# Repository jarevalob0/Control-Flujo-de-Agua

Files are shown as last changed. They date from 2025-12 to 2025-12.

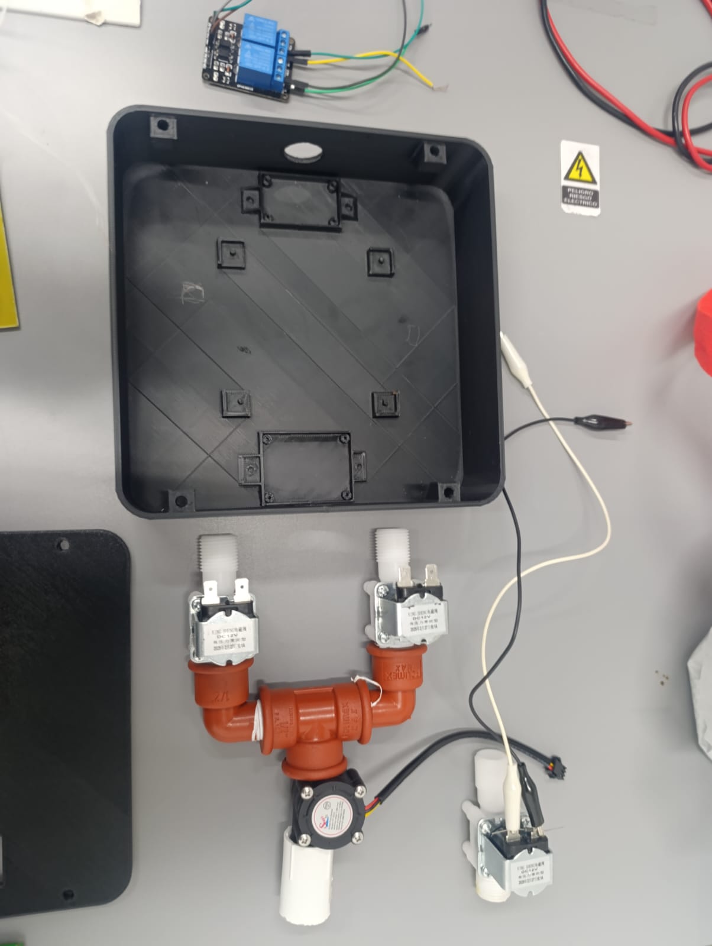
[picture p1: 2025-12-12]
Evidencias/Foto1.jpeg

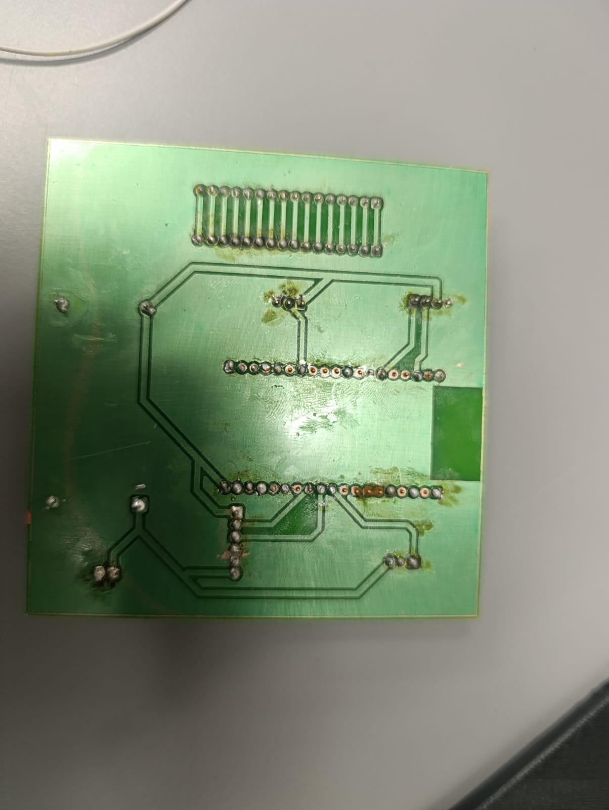
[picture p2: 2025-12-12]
Evidencias/Foto3.jpeg

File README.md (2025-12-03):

# Descripción
Sistema inteligente capaz de medir, registrar y analizar en tiempo real el consumo de agua en viviendas o instalaciones, controlado desde una aplicación móvil.

# Integrantes
SAMUEL CASALLAS

VICTOR ORTIZ

JUAN AREVALO

GABRIEL ALAMO

DANIEL CAMACHO

# Introducción
El proyecto HydroSense surge ante la creciente necesidad de hacer un uso eficiente del agua, un recurso cada vez más limitado debido al cambio climático, el crecimiento poblacional y la falta de sistemas modernos de monitoreo.

En la mayoría de hogares, el consumo de agua no se mide en tiempo real y las personas no tienen forma de saber cuánta agua gastan en actividades comunes. Esto dificulta la adopción de hábitos responsables y limita la capacidad de detectar fugas o consumos inusuales.

HydroSense busca ofrecer una solución de bajo costo que permita medir el uso del agua de manera precisa, accesible y automática, brindando información útil para reducir el desperdicio y promover la conciencia ambiental.

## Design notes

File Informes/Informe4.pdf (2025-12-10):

# CUARTO INFORME PROTOTIPO

### CIRCUITO INTEGRADO A IOT PARA MEDIR Y REDUCIR EL DESPERDICIO DEL AGUA

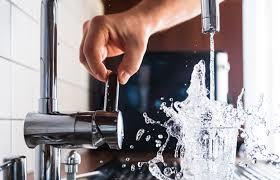
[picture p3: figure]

## EQUIPO

## SAMUEL CASALLAS VICTOR ORTIZ JUAN AREVALO GABRIEL ALAMO DANIEL CAMACHO

INTRODUCCIÓN INGENIERÍA ELECTRÓNICA

1

# OBJETIVO DEL PROTOTIPO

crear una solución innovadora desde la ingeniería electrónica poniendo en práctica conocimientos básicos de los circuitos y nuevas tecnologías

# INTRODUCCIÓN

En el cronograma nos toco lo que es avance de circuito y programación para poder conectar a IOT el prototipo y a la vez documentar errores que hemos cometido por no tener en cuenta ciertos aspectos.

# AVANCES

Ya hemos logrado avanzar con el circuito integrado al ESP32, conectando pantalla LCD con un modulo I2C para simplificar conexiones, conectar los relés y estos conectados a las electroválvulas de 12V.
En cuanto la programación lo que hemos avanzado es calibrar el sensor de flujo y mostrar la información de la cantidad de agua que se esta usando en la pantalla LCD.

ERRORES:

Esta semana compramos la fuente de 12V pero que solo nos da 1 Amperio de corriente, y al tener conectado las electroválvulas en serie y al modulador de voltaje que conecta al ESP32, la corriente que da esta fuente no es suficiente para alimentar todo el sistema del circuito lo que nos genera un atraso en cuanto al cronograma, por lo que la próxima semana se arreglará el problema comprando otra fuente que de la suficiente corriente al sistema.

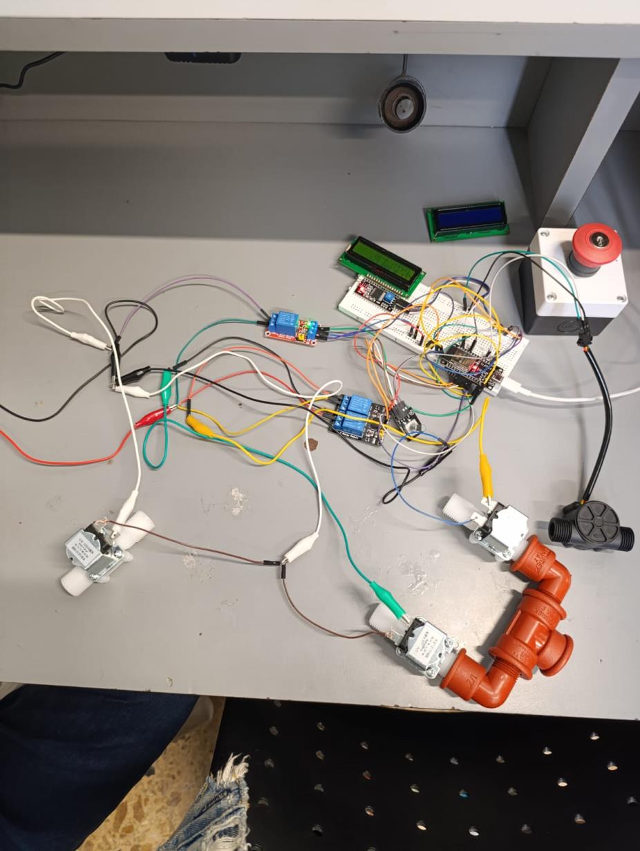
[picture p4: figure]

2

# CONCLUSIONES

Para la próxima semana trabajaremos en arreglar los fallos del circuito, conectar el sistema a IOT y para laboratorio de Electrónica se avanzará con el diagrama esquemático para la creación del PCB.

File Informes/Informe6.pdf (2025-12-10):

# ÚLTIMO INFORME PROTOTIPO

### CIRCUITO INTEGRADO A IOT PARA MEDIR Y REDUCIR EL DESPERDICIO DEL AGUA

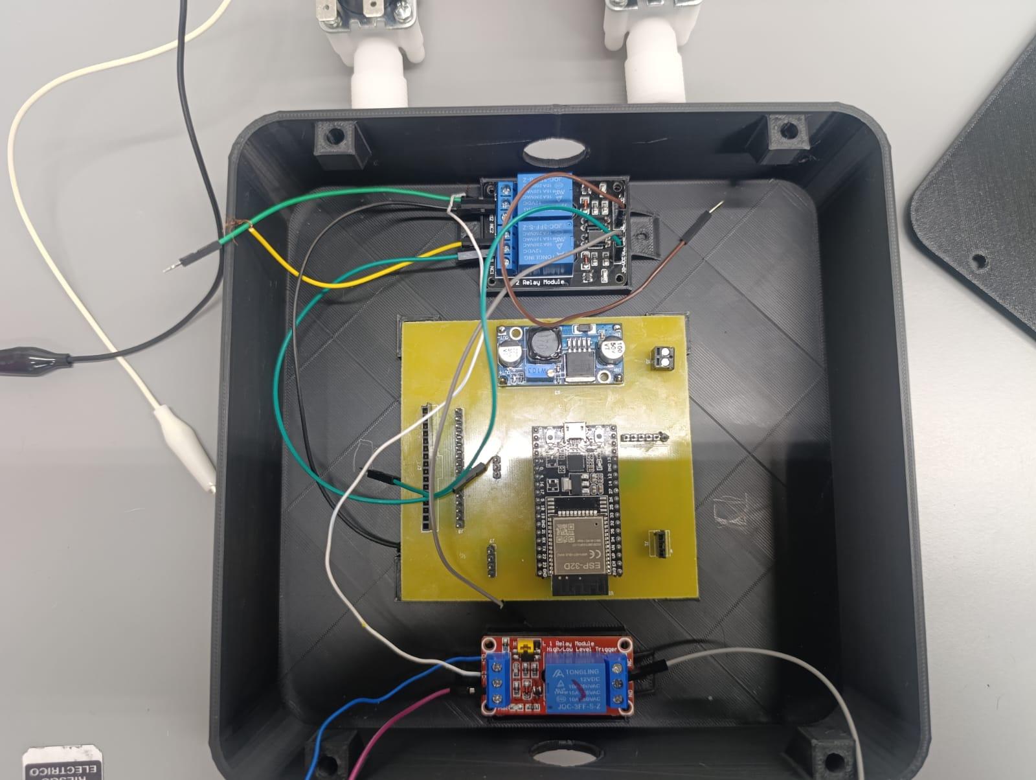
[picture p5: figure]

## EQUIPO: SAMUEL CASALLAS VICTOR ORTIZ JUAN AREVALO GABRIEL ALAMO DANIEL CAMACHO

INTRODUCCIÓN INGENIERÍA ELECTRÓNICA

### OBJETIVO DEL PROTOTIPO

crear una solución innovadora desde la ingeniería electrónica poniendo en práctica conocimientos básicos de los circuitos y nuevas tecnologías

### INTRODUCCIÓN

En nuestro cronograma planificamos que esta semana nos toca la parte de soldar el PCB y el armado del prototipo con su Case correspondiente. Este informe va detallar el avance en estas actividades y lo que nos queda por hacer antes de la fecha de presentación del prototipo que es el 12 de Diciembre.

### AVANCES

Esta semana nos entregaron la PCB fabricada por lo que se soldaron las piezas con las cuales vamos a poder conectar los diferentes componentes al PCB como los relés, pantalla LCD, Electroválvulas y el ESP32.

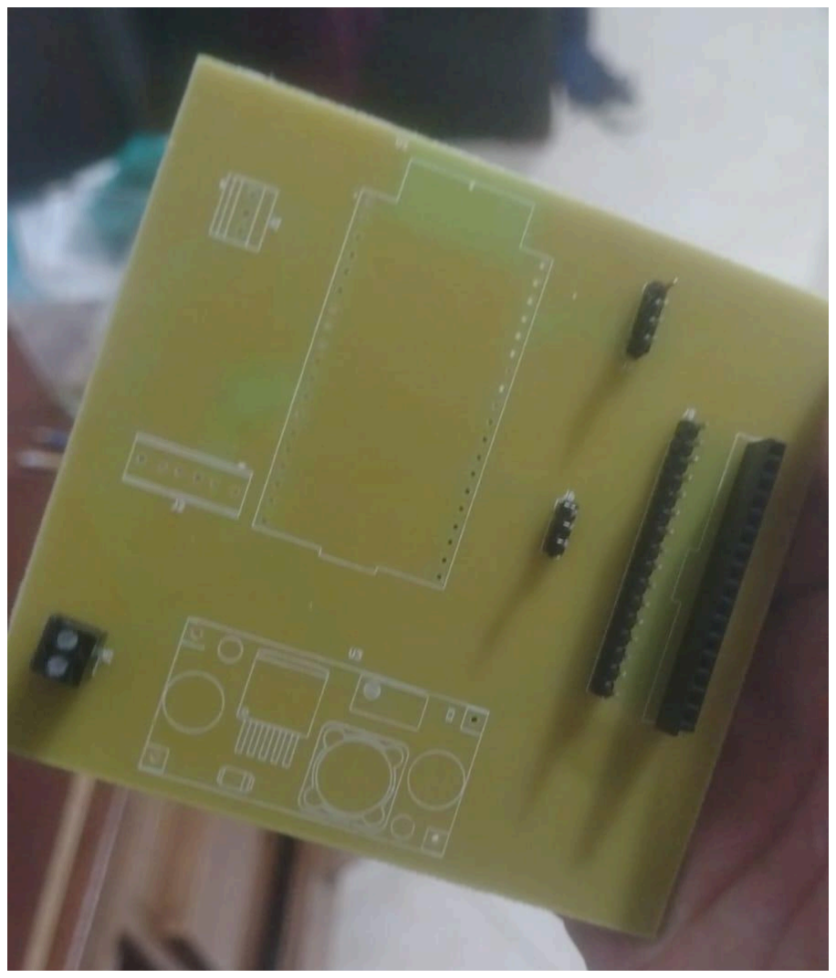
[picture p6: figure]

1

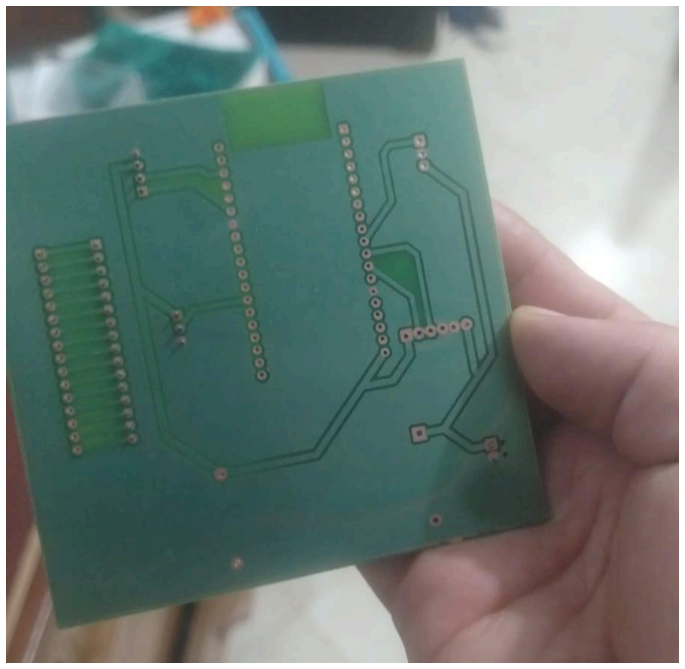
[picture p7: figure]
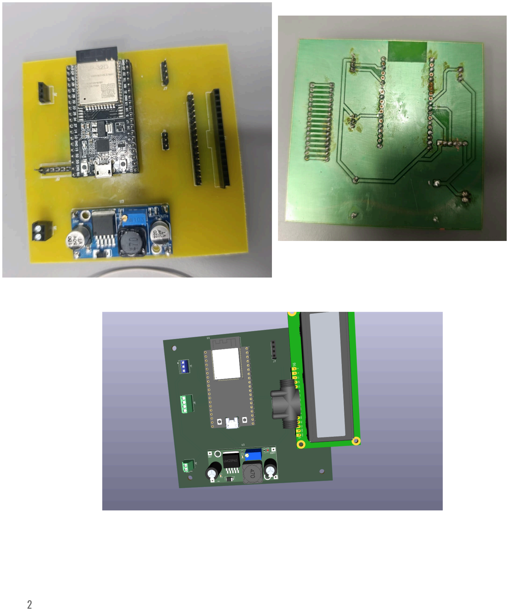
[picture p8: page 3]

2

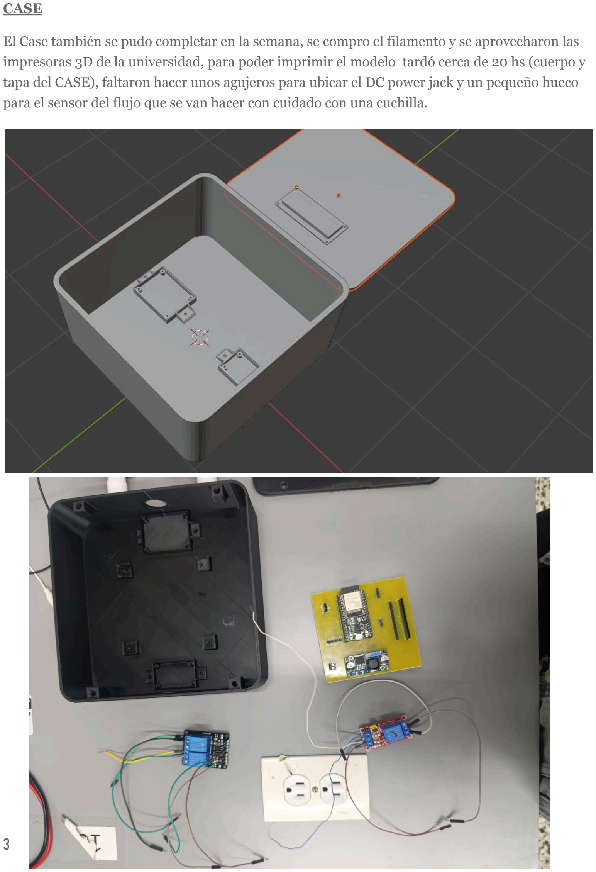
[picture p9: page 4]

CASE

El Case también se pudo completar en la semana, se compro el filamento y se aprovecharon las impresoras 3D de la universidad, para poder imprimir el modelo tardó cerca de 20 hs (cuerpo y tapa del CASE), faltaron hacer unos agujeros para ubicar el DC power jack y un pequeño hueco para el sensor del flujo que se van hacer con cuidado con una cuchilla.

3

### IOT

Se conectó el prototipo a un sistema IOT. se va usar una plataforma con una versión gratuita BLYNK, para controlar el sistema de agua y generar las alertas por el uso excesivo de agua y también poder seleccionar el tipo de agua a usar y sea agua de lluvia o agua potable, hacerlo desde un celular o una computadora conectada a WiFi

4

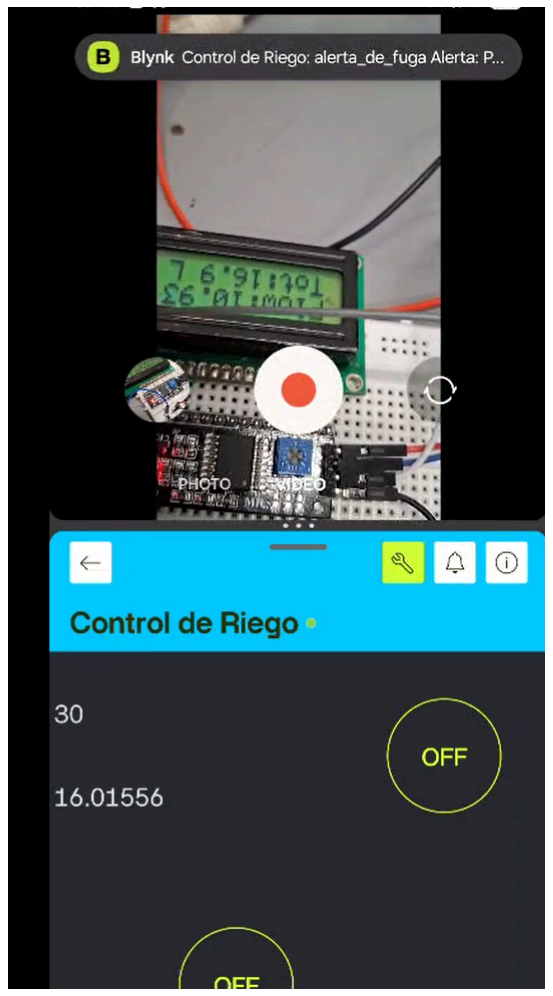
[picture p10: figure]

ERRORES Y ATRASOS

Nuestros errores son de principiantes, esta vez no tuvimos en cuenta en el diseño del case entradas a algunos cables por lo que toca hacer estos ajustes manualmente y con mucho cuidado.

Otro de nuestros errores fue que no sabíamos soldar, además de tener una máquina de soldar en malas condiciones por lo que algunas soldaduras de los pines de la PCB no se ven bien estéticamente.

Con respecto al circuito cuando conectamos todo a la PCB, no funcionaba uno de los relés por lo que sospechamos que pudo haber sido una mala soldadura en el pin que manda los comandos o los cables están en mal estado.

### Lo que nos falta

Para la entrega del prototipo realizaremos los ajustes necesarios a partir de las fallas detectadas en las pruebas previas. Además, evaluaremos su desempeño integrado en un sistema de agua real con el fin de validar su funcionamiento en un entorno operativo.

Como parte de la documentación del proyecto, produciremos un video explicativo que muestre de manera clara el funcionamiento del prototipo. También avanzaremos en el diseño del brochure publicitario, procurando que sea visualmente atractivo, informativo y alineado con la identidad del proyecto.

5

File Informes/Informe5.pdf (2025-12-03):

# QUINTO INFORME PROTOTIPO

### CIRCUITO INTEGRADO A IOT PARA MEDIR Y REDUCIR EL DESPERDICIO DEL AGUA

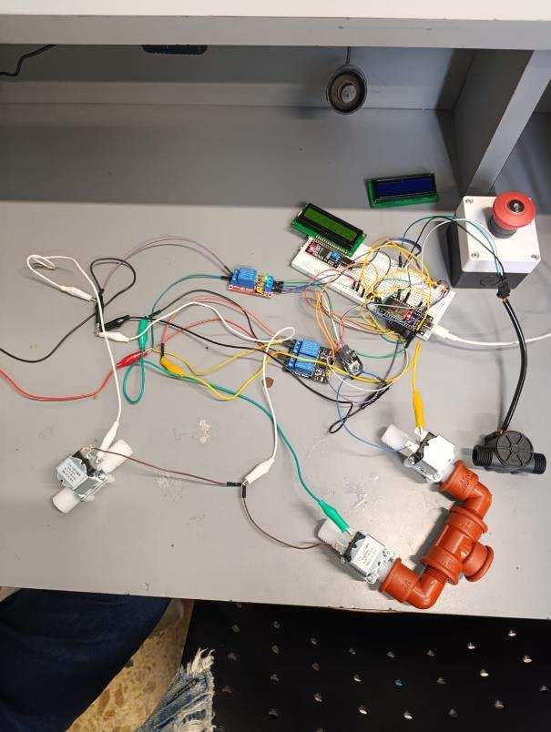
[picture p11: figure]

## EQUIPO: SAMUEL CASALLAS VICTOR ORTIZ JUAN AREVALO GABRIEL ALAMO DANIEL CAMACHO

INTRODUCCIÓN INGENIERÍA ELECTRÓNICA

# OBJETIVO DEL PROTOTIPO

crear una solución innovadora desde la ingeniería electrónica poniendo en práctica conocimientos básicos de los circuitos y nuevas tecnologías

# INTRODUCCIÓN

En este informe hablaremos de avances que llevamos con laboratorio de electrónica, errores y lo que nos queda por hacer en las semanas que quedan.

# AVANCES

En laboratorio de electrónica se nos propuso hacer el PCB y un CASE para el prototipo que se está armando.
Ya se logró terminar el diseño de La PCB por lo que nos falta que profesor de laboratorio revisé nuestro diseño para luego mandar a fabricar la placa y proceder a soldar los componentes a la misma. El encargado de la PCB es Samuel casallas que también esta trabajando con Víctor Ortiz en el circuito.

En cuanto al circuito, todavía se esta viendo que el golpe electromagnético de las electroválvulas cuando prenden y apaga no afecte al microcontrolador

# Adelanto PCB

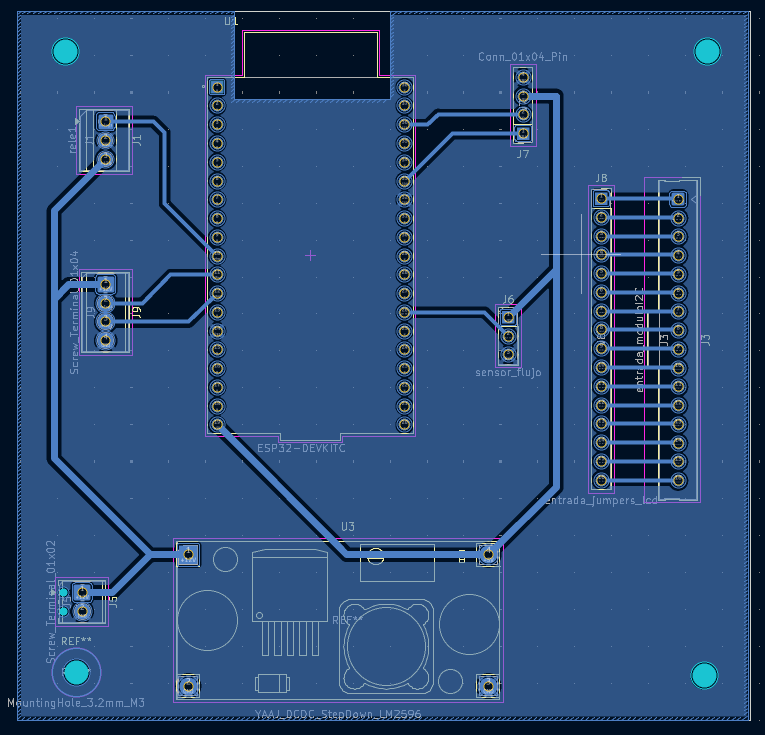
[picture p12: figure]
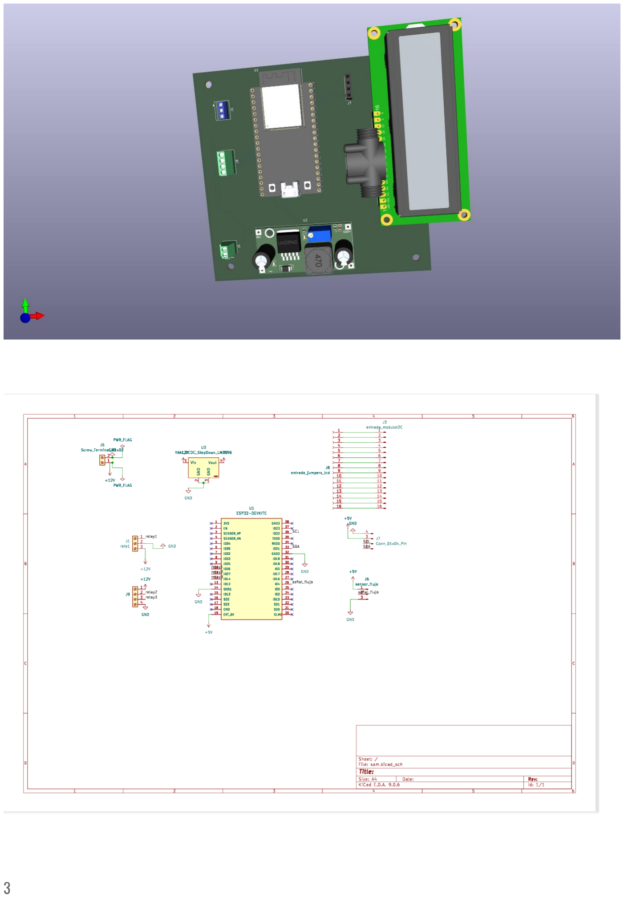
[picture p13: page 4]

CASE

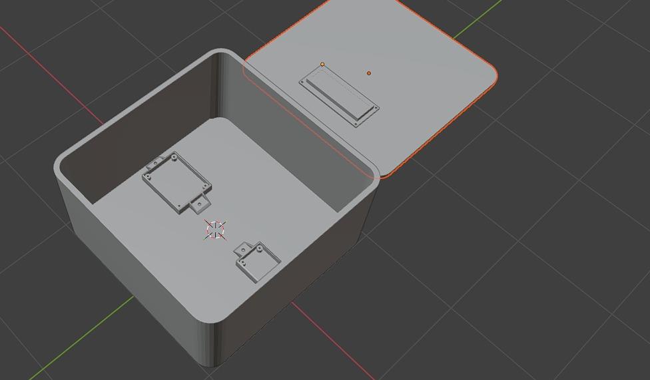
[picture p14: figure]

Todavía falta darle mas diseño al case, aun se sigue trabajando en el case para ya la próxima semana mandar a fabricar el case y hacer primeras pruebas con el circuito.

ERRORES Y ATRASOS:

En la semana tuvimos una falla, mientras hacíamos el circuito de 12V que conecta a los relés y las electroválvulas conectamos por error el ESP32 a la fuente de 12V lo que nos quemo el microcontrolador, un error que facilito el diseño de la PCB ya que el footprint del ESP32 que se quemó no se encontraba en internet y el que se compró si se encontró fácilmente.
Esta semana nuestro compañero Juan Arévalo el encargado de la programación y comunicación del ESP32 con un sistema IOT no realizo avances por lo que en este sector no se realiza documentación por ahora

# CONCLUSIONES

Esperamos que el profesor de laboratorio nos de el ok con el modelo de la PCB así poder proseguir a soldar los componentes y sumarlo al case para llegar a la fecha de presentación del prototipo y poder probarlo con un sistema de agua.

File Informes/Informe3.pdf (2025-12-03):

# TERCER INFORME PROTOTIPO

### CIRCUITO INTEGRADO A IOT PARA MEDIR Y REDUCIR EL DESPERDICIO DEL AGUA


## EQUIPO

## SAMUEL CASALLAS VICTOR ORTIZ JUAN AREVALO GABRIEL ALAMO DANIEL CAMACHO

INTRODUCCIÓN INGENIERÍA ELECTRÓNICA

# INTRODUCCIÓN

Esta semana se ha adelantado con otras componentes que nos van ayudar con la conexión del circuito y cuidando cada componente de no dañarlos y a la vez también se adelanta en la documentación de laboratorio de electrónica.

# OBJETIVO DEL PROTOTIPO

crear una solución innovadora desde la ingeniería electrónica poniendo en práctica conocimientos básicos de los circuitos y nuevas tecnologías

# COMPONENTES ELECTRÓNICOS

1. Caudalímetro
2. electroválvulas
3. Microprocesador ESP32
4. Arduino
5. IOT
6. Pantalla LCD 16x2

Estos componentes son los que compramos la semana pasada, y esta semana se compraron mas componentes para poder facilitar las conexiones de los circuitos y cuidar de no dañar los componentes.

7. Relés de 12V a 3.3V
8. Un cargador de 12V y con corriente de 1ª
9. Un I2C para simplificar conexiones de la pantalla LCD

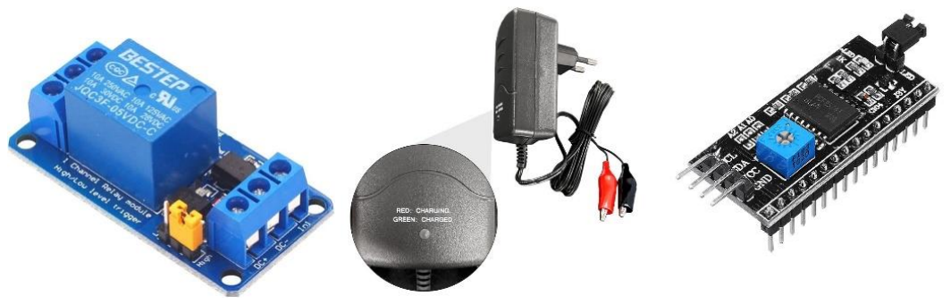
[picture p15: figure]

# DIAGRAMA CAJA NEGRA

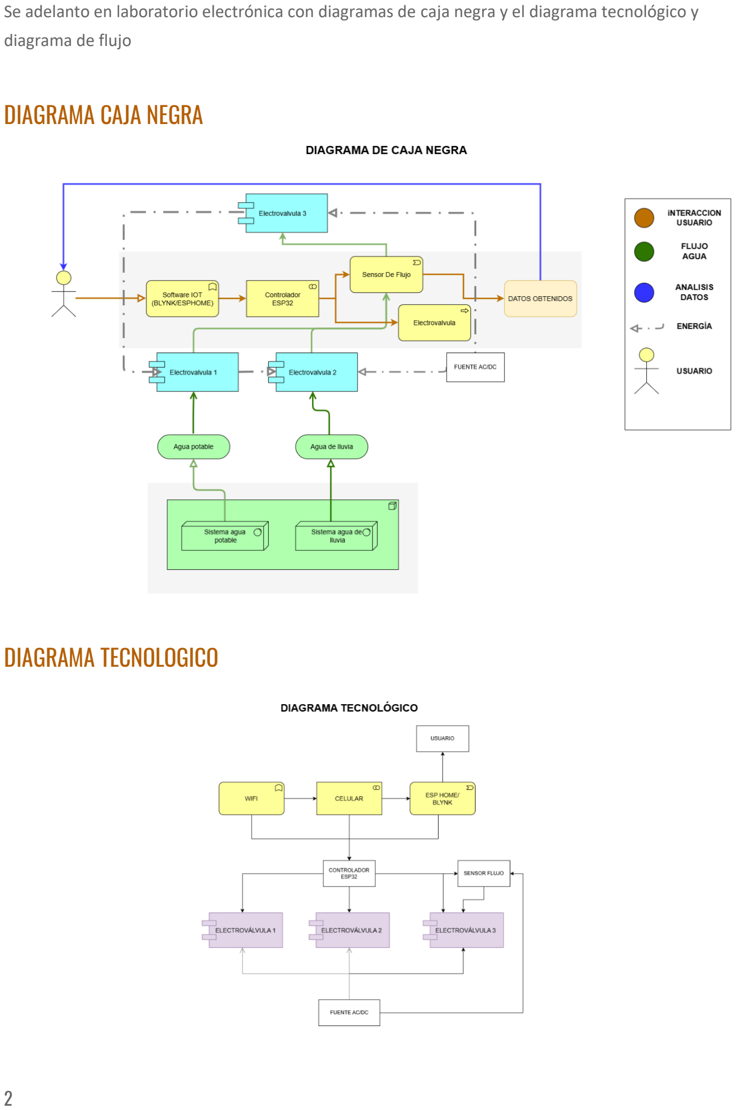
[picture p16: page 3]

Se adelanto en laboratorio electrónica con diagramas de caja negra y el diagrama tecnológico y diagrama de flujo

# DIAGRAMA TECNOLOGICO

# DIAGRAMA DE FLUJO

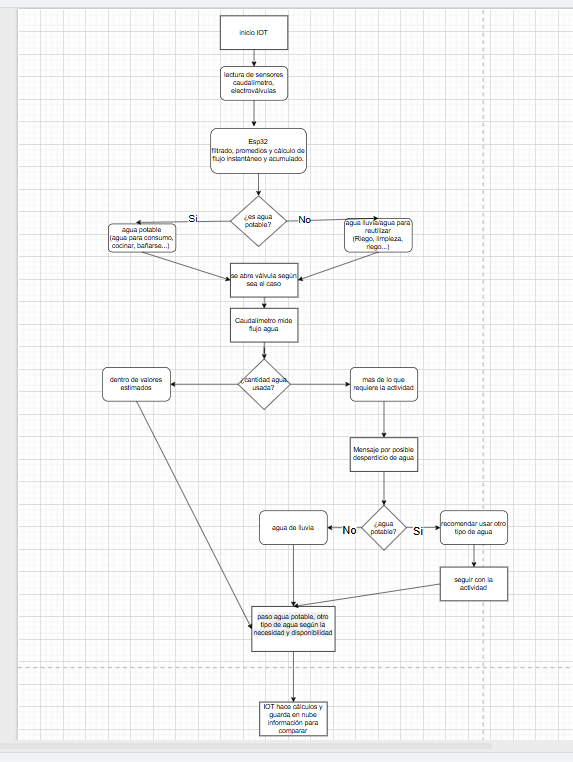
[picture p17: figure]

# CONCLUSIONES

La próxima semana se dedicara a trabajar en solo el diagrama de conexiones, montar el circuito, calibración del sensor.

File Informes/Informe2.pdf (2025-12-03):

# SEGUNDO INFORME PROTOTIPO

CIRCUITO INTEGRADO A IOT PARA MEDIR Y REDUCIR EL DESPERDICIO DEL AGUA

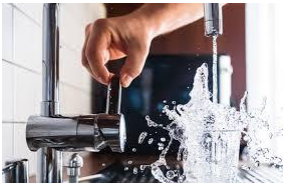
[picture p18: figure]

## EQUIPO

## SAMUEL CASALLAS VICTOR ORTIZ JUAN AREVALO GABRIEL ALAMO DANIEL CAMACHO

INTRODUCCIÓN INGENIERÍA ELECTRÓNICA

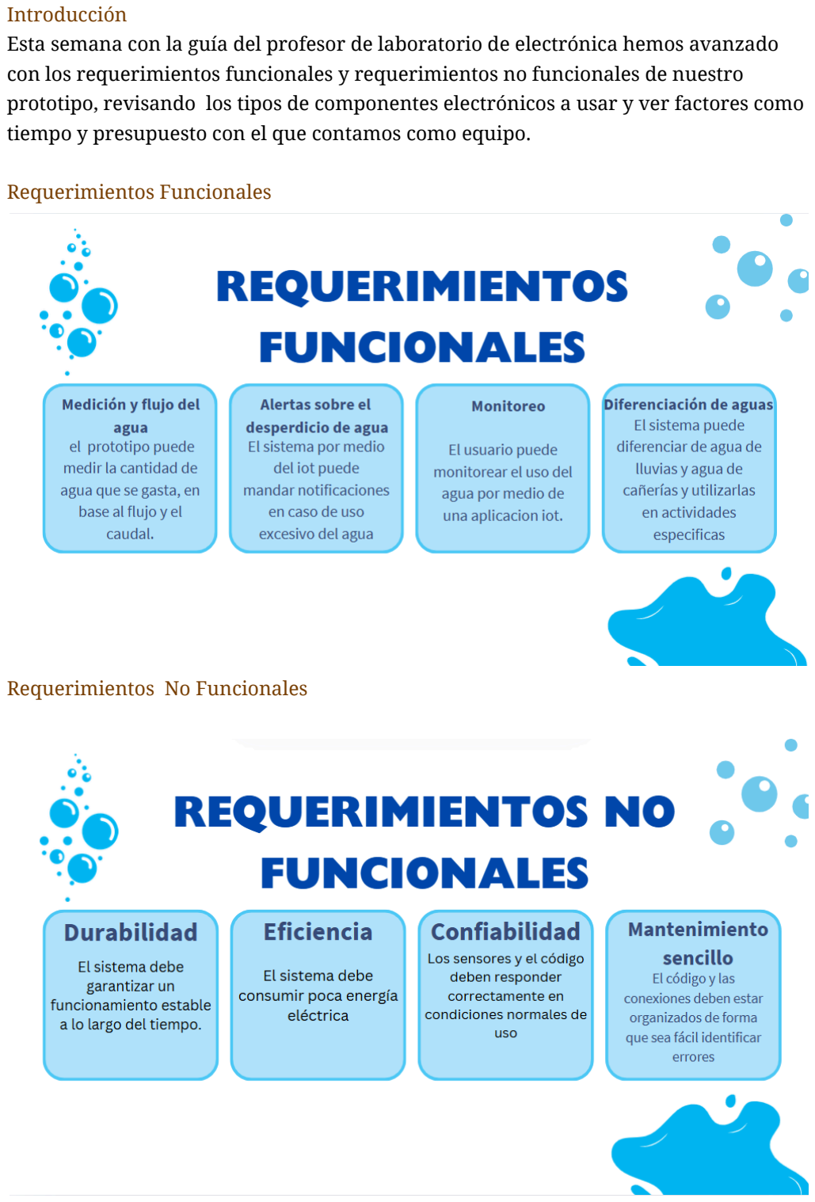
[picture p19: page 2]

Introducción
Esta semana con la guía del profesor de laboratorio de electrónica hemos avanzado con los requerimientos funcionales y requerimientos no funcionales de nuestro prototipo, revisando los tipos de componentes electrónicos a usar y ver factores como tiempo y presupuesto con el que contamos como equipo.

Requerimientos Funcionales

Requerimientos No Funcionales

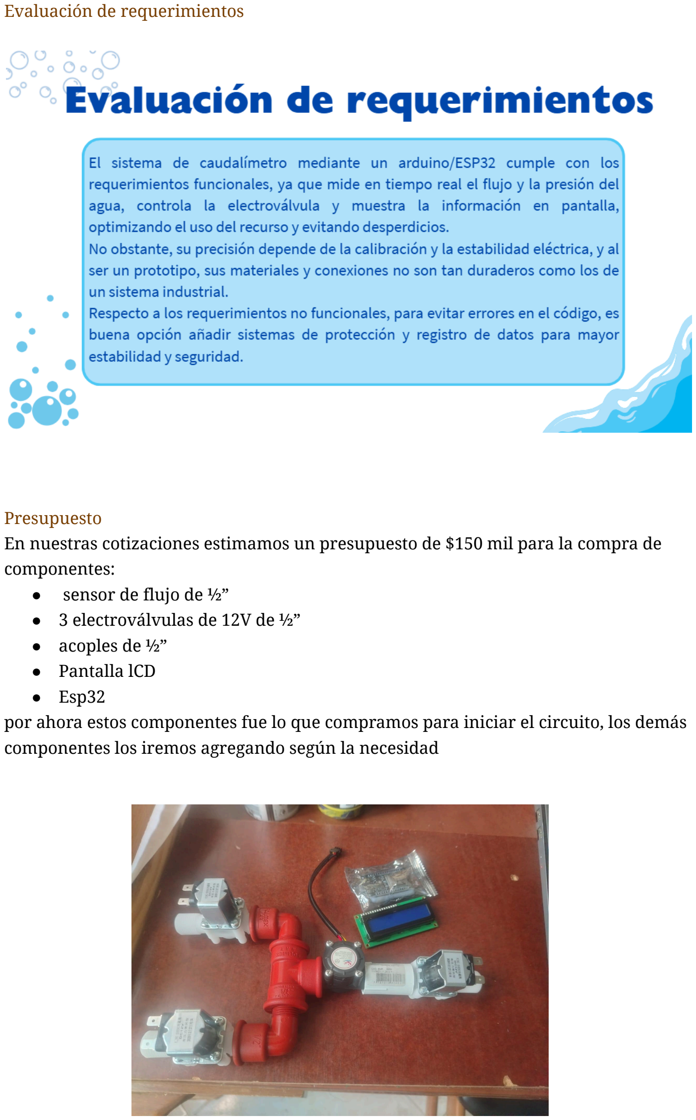
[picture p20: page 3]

Evaluación de requerimientos

Presupuesto
En nuestras cotizaciones estimamos un presupuesto de $150 mil para la compra de componentes:
- sensor de flujo de ½”
- 3 electroválvulas de 12V de ½”
- acoples de ½”
- Pantalla lCD
- Esp32
por ahora estos componentes fue lo que compramos para iniciar el circuito, los demás componentes los iremos agregando según la necesidad

Diagrama De Flujo del prototipo

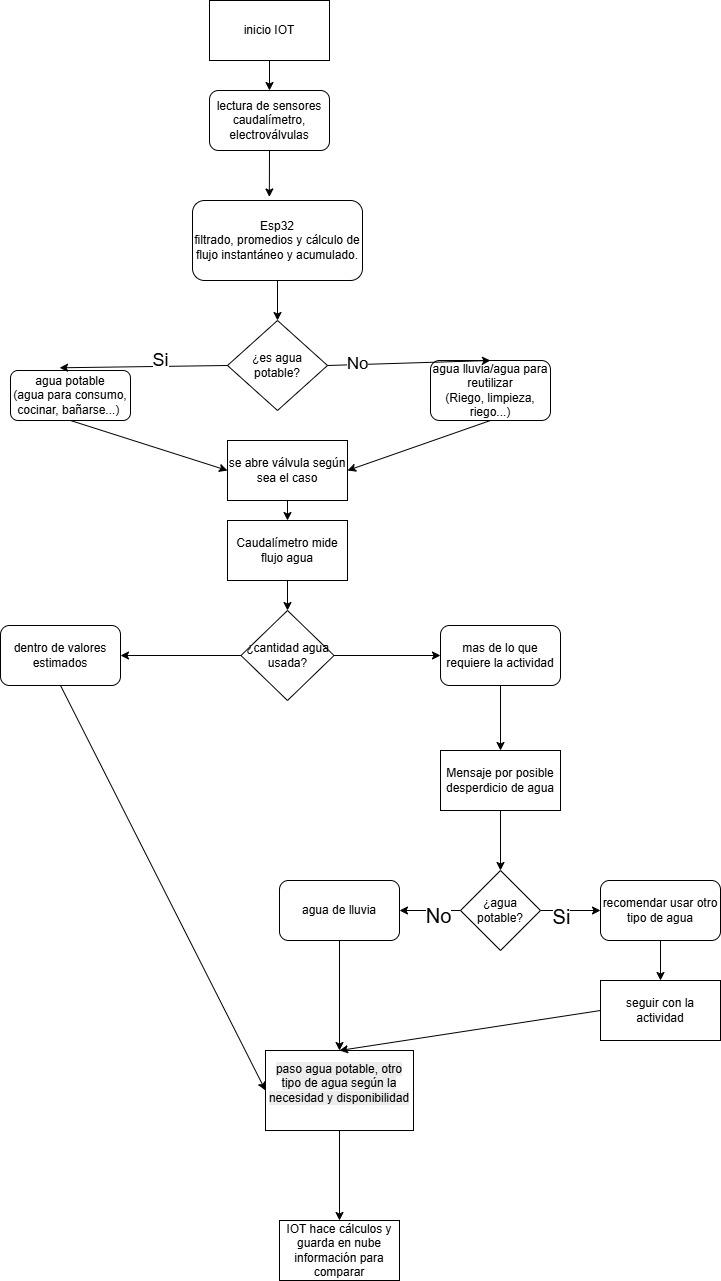
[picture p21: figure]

Conclusiones
Para la próxima semana según nuestro cronograma estaremos trabajando en el circuito, calibración del sensor y ajustando la programación del sensor de flujo, a la vez estaremos trabajando en la documentación del taller de laboratorio de electrónica.

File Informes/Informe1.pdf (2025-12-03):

# PRIMER INFORME PROTOTIPO

CIRCUITO INTEGRADO A IOT PARA MEDIR Y REDUCIR EL DESPERDICIO DEL AGUA

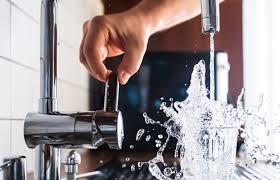
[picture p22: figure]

## EQUIPO

## SAMUEL CASALLAS VICTOR ORTIZ JUAN AREVALO GABRIEL ALAMO DANIEL CAMACHO

INTRODUCCIÓN INGENIERÍA ELECTRÓNICA

## INTRODUCCIÓN

En el cronograma estipulamos que esta primera semana investigaremos acerca de los componentes electrónicos que vamos a utilizar en el prototipo dando una solución a nuestra problemática que es el desperdicio de agua, a su vez explicaremos qué ventajas, desventajas y los límites de estos componentes

## OBJETIVO DEL PROTOTIPO

crear una solución innovadora desde la ingeniería electrónica poniendo en práctica conocimientos básicos de los circuitos y nuevas tecnologías

## COMPONENTES ELECTRÓNICOS

1. Caudalimetro
2. electroválvulas
3. Microprocesador ESP32
4. Arduino
5. IOT

Ahora daremos paso a explicar el porqué usaremos cada uno de los componentes y con qué finalidad, así como sus ventajas y desventajas.

1

## CAUDALIMETRO

Para el prototipo usaremos un sensor de flujo de agua YF-S201 de ¾” qué va medir el paso del agua, el sensor funciona mediante un rotor interno que gira con el paso del agua. Este movimiento hace que un imán dentro del rotor pase repetidamente por un sensor de efecto hall, el cual genera una señal de pulsos y esté conectado a un arduino o microprocesador nos permitirá calcular el caudal de agua que pasa.

Este sistema nos permitirá calcular la cantidad de agua que se está usando para cierta actividad y trabajar con estos datos desde un software y hacer estimaciones de consumo de agua para las actividades en que se usa.

como limitante de este componente electrónico es que por diseño este sensor sólo puede calcular caudales de 1 litros/min-30 litros/min lo que no no va medir si hay fuga en el sistema si no supera ese valor mínimo de 1 litro/min, además de su área de sección es de ¾” lo que sirve para conecciones con mangueras o pvc de este diámetro únicamente, también son susceptibles a atorarse con mugre del agua que se va acomulando, lo que requiere una limpieza del componente.

2

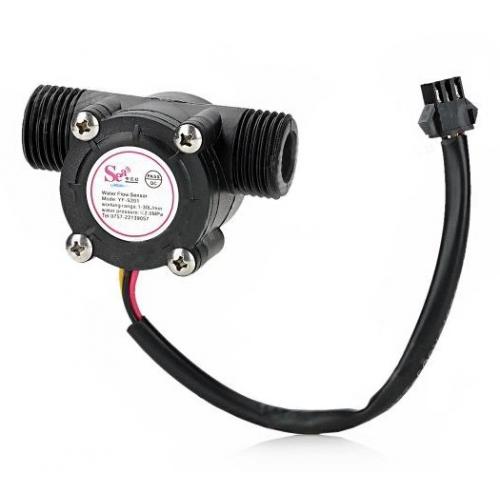
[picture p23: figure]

## ELECTROVÁLVULAS

Elegimos las electroválvulas porque nos permiten controlar de forma automática el paso del agua dentro del sistema, sin tener que hacerlo manualmente. Este componente se activa mediante una señal eléctrica del microcontrolador, abriéndose o cerrándose según las condiciones del circuito.

También cumple otra función: regular el flujo de agua durante cada actividad, evitando desperdicios y permitiendo medir con precisión el consumo real. Esta nos permite que el sistema pueda detener el paso del agua cuando no se está utilizando o cuando se alcanza el volumen establecido , haciendo el proceso más eficiente y controlado.

En nuestro proyecto se plantea el uso de dos fuentes de agua: el agua del sistema de acueducto y el agua de lluvia recolectada. Para controlar el flujo desde cada fuente se utilizaran dos electroválvulas, una en la entrada que regula de donde proviene el agua, y otra en la salida que controla cuando se libera el caudal hacia la actividad correspondiente.

El sistema dará prioridad al uso del agua de lluvia, aprovechando este recurso natural y reduciendo la dependencia del acueducto. De esta manera se busca optimizar el consumo de agua potable, fomentar el uso sostenible de los recursos hídricos y disminuir el desperdicio, integrando la medición de caudal y el control automático mediante las electroválvulas.

3

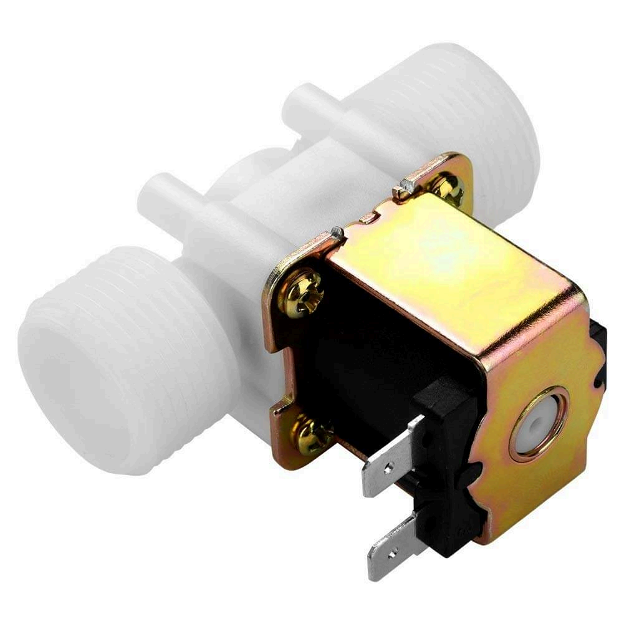
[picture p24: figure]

## MICROPROCESADOR ESP32

El ESP32 es un microprocesador programable que recibe información de sensores, la procesa y controla otros dispositivos (como bombas, válvulas o motores) de forma automática o remota.

El ESP32 es el encargado de leer, interpretar y procesar la información que es generada por el caudalímetro. Gracias a la capacidad del microprocesador de poder conectarse a una red wifi o bluetooth se usará para subir los datos a la nube y poder monitorearlos desde una aplicación de forma remota o para almacenar los datos del consumo total.

## IOT:

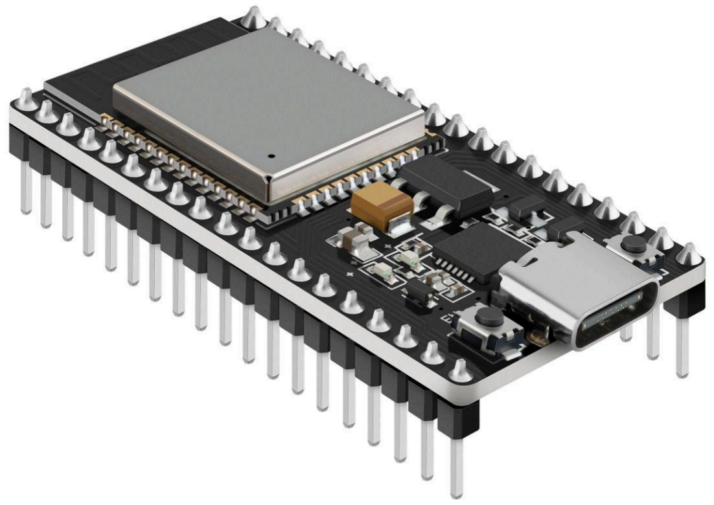
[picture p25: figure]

Usaremos la plataforma Blynk 2.0, para involucrar el IOT en nuestro proyecto, nos permitirá conectar el controlador esp32 a la nube para poder manejar nuestro proyecto con una aplicación desde nuestro celular. Esta aplicación tendrá como principales funciones el monitoreo del flujo de agua, poder calcular el agua necesaria para la actividad que desee el usuario, pudiendo éste configurar el agua que se quiera usar para la actividad que elija, y dar la opción al usuario de poder manejar el mismo las electroválvulas. Ventajas: La plataforma cuenta con un plan gratuito, lo que nos abarata los costes del proyecto. Desventajas: Este plan gratuito nos limita en la cantidad de dispositivos que pueden estar conectados, también solo almacena datos de por un tiempo limitado de una semana, lo cual podría ser un problema a futuro.

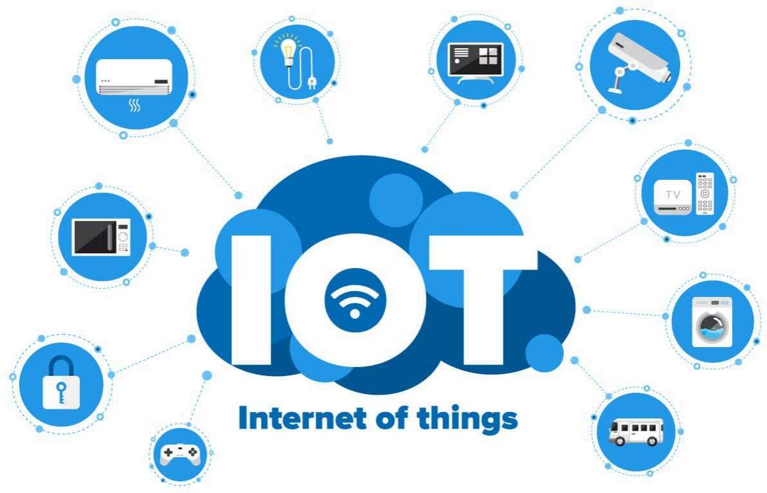
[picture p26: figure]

4

## ARDUINO

El Arduino es el componente principal del sistema de control, este funciona como el cerebro del prototipo, ya que su función es recibir toda la información que le envían los distintos sensores, procesar esos datos para luego ejecutar las acciones programadas, como en el caso de nuestro proyecto, abrir o cerrar la válvula de paso de agua mediante una electroválvula controlada electrónicamente.

Se decidió usar el arduino porque ofrece una manera sencilla
y simple de programar al estar basado en el lenguaje de
C/C++, ya que permite escribir y cambiar el código con


facilidad. Además de esto el arduino tiene la capacidad de ser compatible con un montón de sensores, lo que en nuestro caso, nos facilita la conexión del caudalímetro o el sensor de presión. Su bajo costo y disponibilidad lo hace de las mejores opciones para proyectos de este estilo, sin necesidad de tener equipos industriales costosos.

Dentro del contexto del proyecto, la funcionalidad del arduino es, en primer lugar, recibir las señales eléctricas enviadas por los sensores y las convierte en valores numéricos (como litros por minuto o presión PSI). Luego, analiza los datos en tiempo real y los compara con los límites previamente establecidos, de esa forma poder controlar el flujo del agua de forma automática. Finalmente, el Arduino también se encarga del monitoreo del sistema, permitiendo visualizar la información en una pantalla. Esto facilita observar parámetros como el caudal, la presión o el tiempo de uso.

5

## CONCLUSIÓN

Con la investigación definimos qué componentes electrónicos pueden ser de utilidad para nuestro prototipo y qué papel jugarán en el circuito, el reto será coordinar estos componentes para realizar el objetivo que nos propusimos con nuestro prototipo integrando otros componentes electrónicos como cables, resistencias, etc.

## REFERENCIAS

1. https://alfaiot.com/iot/que-es-arduino-todo-lo-que-necesitas-saber/
2. https://electronilab.co/tienda/electrovalvula-valvula-selenoide-agua-12-vdc-3-4/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
3. https://laredelectronica.com/wp-content/uploads/2020/04/2-16.jpg

6

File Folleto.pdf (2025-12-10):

## ¿ P O R Q UE N E C ESI T AMO S U N A


## SISTEMA I N TELIGE N TE?

# SISTEMA

Q UE MI D E,

# D ETE C T A Y

C O N T R O L A .

## H A Z TU C O N SUMO D E AGUA MÁ S EFI C IE N TE. ¡ P RUÉBA L A !

## TU S O LUC I Ó N : U N SISTEMA Q UE

P IE N S A P O R T I.

## SISTEMA I N TELIGE N TE US O D E AGUA

- DESPERDICIO INNECESARIO
DE AGUA
- AUMENTO EN LA FACTURA
DEL SERVICIO
- USO INEFICIENTE DE AGUA
POTABLE PARA TAREAS
BÁSICAS
- FALTA DE CONTROL Y
VISIBILIDAD DEL CONSUMO
REAL

EL CONSUMO DIARIO DE AGUA ES MAYOR DE LO QUE CREEMOS. MUCHAS VECES USAMOS AGUA POTABLE PARA TAREAS SIMPLES SIN DARNOS CUENTA DEL COSTO NI DEL IMPACTO AMBIENTAL. A ESTO SE SUMA QUE LA MAYORÍA DE PERSONAS NO SABE CUÁNTOS LITROS CONSUME AL REGAR, LAVAR O LIMPIAR, Y TAMPOCO DISTINGUE SI ESTÁ USANDO AGUA DE LLUVIA O AGUA POTABLE, LO QUE GENERA:

AHORRA AGUA, REDUCE
COSTOS Y USA SOLO LO
NECESARIO CON TOTAL
PRECISIÓN.

### - PANTALLA LED CON LECTURA EXACTA DE LITROS POR MINUTO - DETECCIÓN AUTOMÁTICA DE AGUA POTABLE O DE LLUVIA - VÁLVULAS INTELIGENTES SEGÚN TIPO DE AGUA - CONTROL TOTAL PARA EVITAR DESPERDICIOS

# ESPECIFICACIONES TÉCNICAS

TAREA.; US A R AGUA N U N C A H ABÍ A SI D O T A N I N TELIGE N TE; H A Z D E TU C O N SUMO U N A A C C I Ó N R ES P O N S ABLE

BE N EFI C I O S Q UE
T R A N SF O RMA N
TU C O N SUMO

MATERIAL DE LA MANGUERA: PVC
REFORZADO DE ALTA RESISTENCIA
RANGO DE MEDICIÓN: 1–60 LITROS
POR MINUTO
PRECISIÓN DEL CAUDALÍMETRO:
PANTALLA: LED RETROILUMINADA
DE ALTO CONTRASTE
SENSORES: IDENTIFICAN
AUTOMÁTICAMENTE AGUA
POTABLE O AGUA DE LLUVIA
VÁLVULAS: APERTURA Y CIERRE
AUTOMÁTICO SEGÚN TIPO DE
AGUA DETECTADA
CONECTORES: COMPATIBLES CON
GRIFOS ESTÁNDAR
ALIMENTACIÓN DEL MÓDULO:
BATERÍA RECARGABLE POR USB
LONGITUDES DISPONIBLES: 5 M, 10
GARANTÍA: 1 AÑO CONTRA
DEFECTOS DE FABRICACIÓN

• AHORRA AGUA GRACIAS A
LA MEDICIÓN PRECISA DEL

CAUDAL.
• REDUCE TU FACTURA
CONTROLANDO CUÁNTOS
LITROS USAS EN CADA

NUESTRO SISTEMA INTELIGENTE TE
AYUDA A CONTROLAR TU CONSUMO DE
AGUA, EVITAR EL DESPERDICIO Y
OPTIMIZAR CADA USO DIARIO.
APROVECHA MEJOR EL AGUA DE
LLUVIA, USA AGUA POTABLE SOLO
CUANDO ES NECESARIO Y DISFRUTA DE
UNA TECNOLOGÍA PENSADA PARA
CUIDAR TU BOLSILLO Y TU ENTORNO.

• APROVECHA EL AGUA DE
LLUVIA DE FORMA
AUTOMÁTICA Y SEGURA.
• EVITA EL DESPERDICIO DE
AGUA POTABLE, USÁNDOLA

SOLO DONDE
CORRESPONDE.
• IDEAL PARA RIEGO,
LIMPIEZA, AUTOS Y
MANTENIMIENTO DIARIO.
• MAYOR SEGURIDAD: EVITA
MEZCLAR AGUA NO APTA EN
TAREAS SENSIBLES.
• INSTALACIÓN RÁPIDA Y
USO INTUITIVO.

¡ D A EL PA S O H AC I A U N CO N SUMO MÁ S

I N TEL IGE N TE Y EFI C IE N TE!

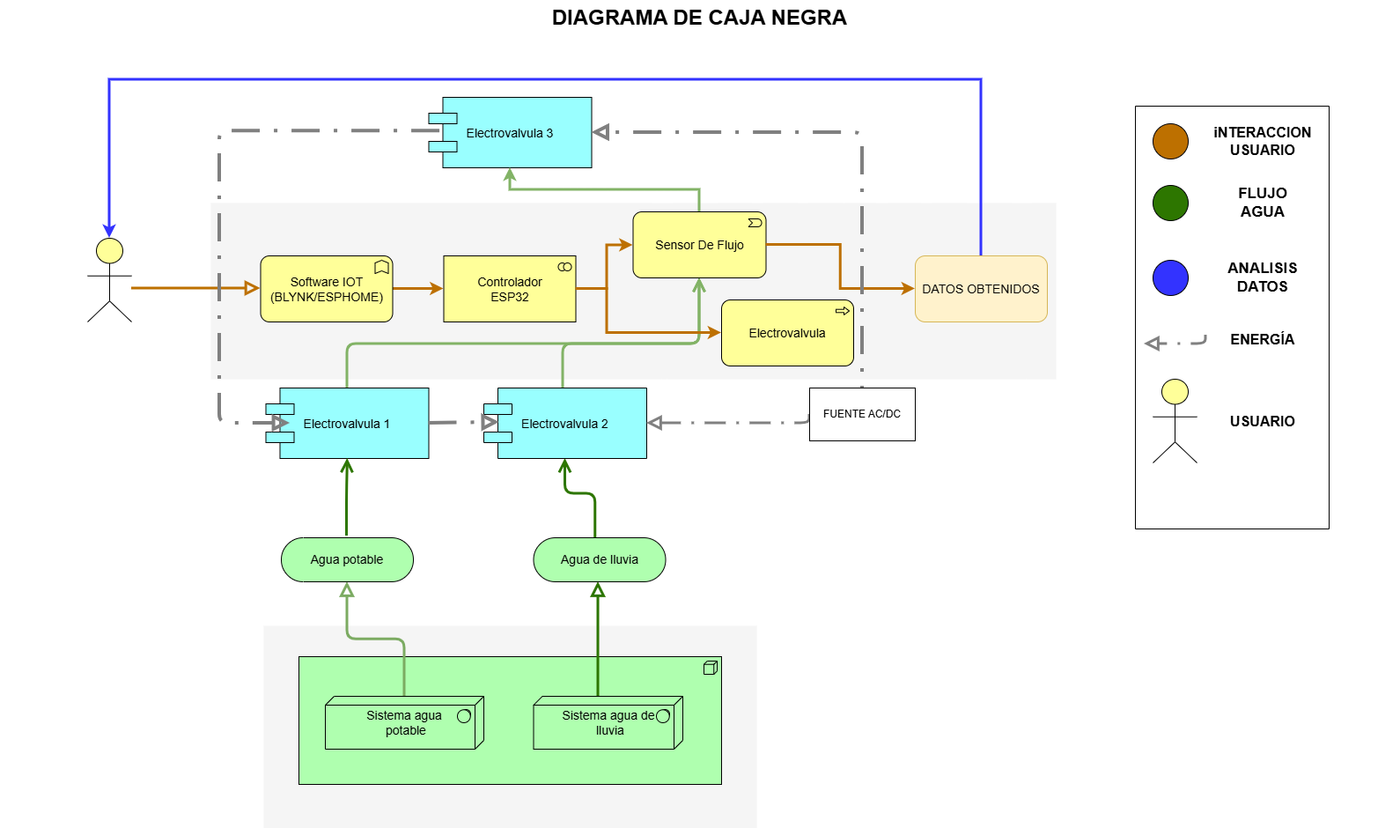
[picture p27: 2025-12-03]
Diagramas/DiagramaDeCaja.png

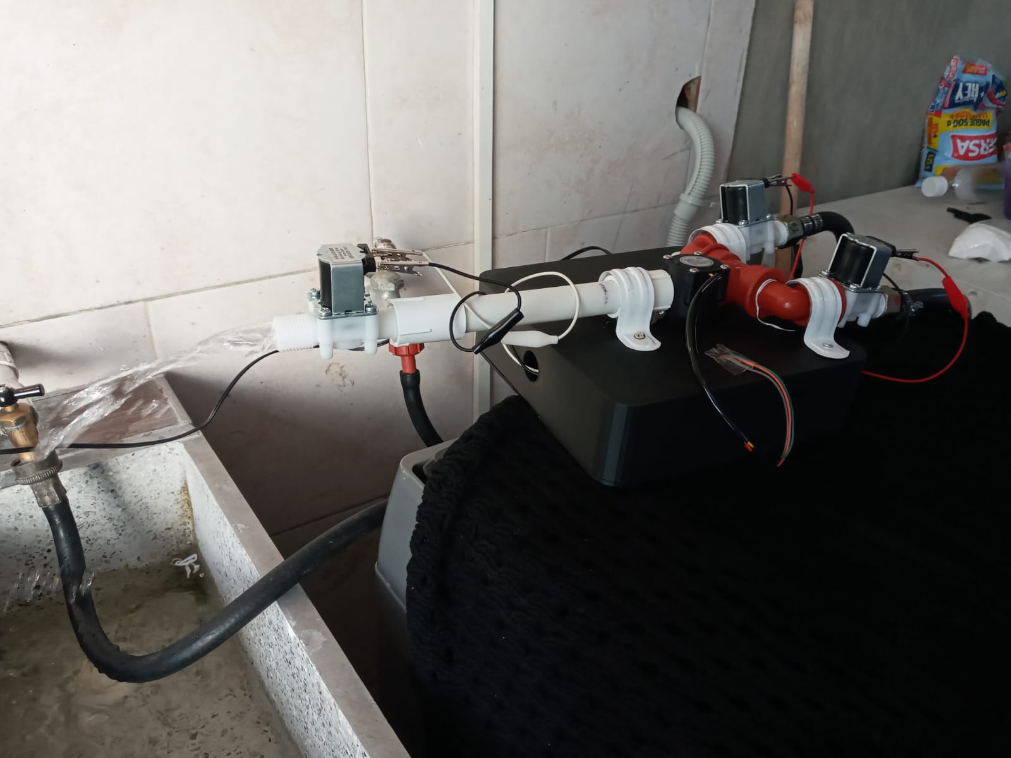
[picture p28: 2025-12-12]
Evidencias/Foto8.jpeg

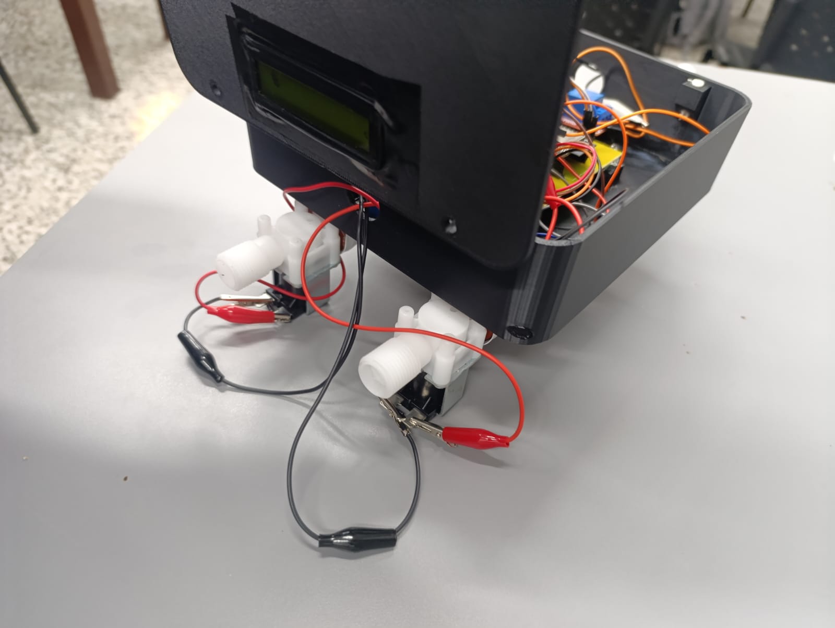
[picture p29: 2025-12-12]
Evidencias/Foto5.jpeg

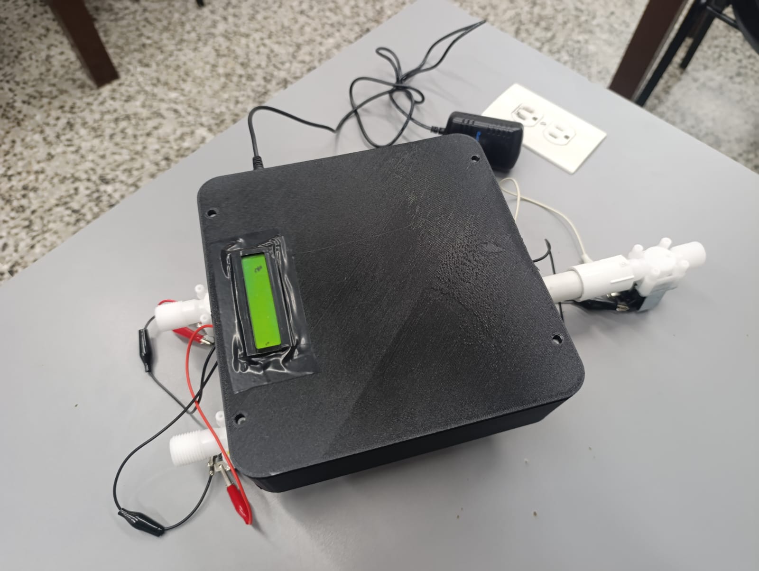
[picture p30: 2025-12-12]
Evidencias/Foto4.jpeg

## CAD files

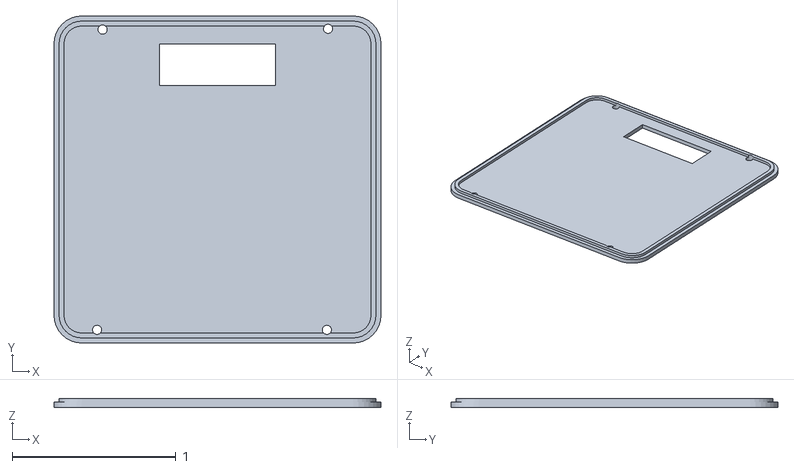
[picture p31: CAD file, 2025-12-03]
CASE/diseño case2.stl
2.00 x 2.00 x 0.0546

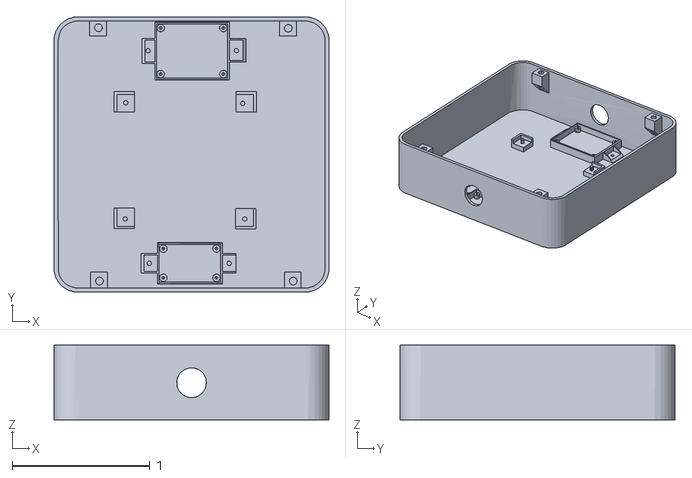
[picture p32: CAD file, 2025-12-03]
CASE/diseño case1.stl
2.00 x 2.00 x 0.542

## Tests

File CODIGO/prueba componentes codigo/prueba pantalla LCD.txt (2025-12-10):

Pantalla LCD
#include <Wire.h>
#include <LiquidCrystal_I2C.h>

// Dirección I2C típica del módulo LCD (usa 0x27 o 0x3F)
LiquidCrystal_I2C lcd(0x27, 16, 2);  // (Dirección, columnas, filas)

void setup() {
  Wire.begin(21, 22);  // SDA=21, SCL=22 para ESP32
  lcd.init();           // Inicializa el LCD
  lcd.backlight();      // Enciende la luz de fondo
  
  lcd.setCursor(0, 0);
  lcd.print("Hola ESP32!");
  lcd.setCursor(0, 1);
  lcd.print("LCD funcionando");
}

void loop() {
  // Ejemplo de texto animado
  lcd.setCursor(0, 1);
  lcd.print("Contador: ");
  lcd.print(millis() / 1000); // Segundos desde inicio
  delay(1000);
}

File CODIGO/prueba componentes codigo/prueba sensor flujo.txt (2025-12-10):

#include <Wire.h>
#include <LiquidCrystal_I2C.h>

#define SENSOR_FLUJO_PIN 4     // Sensor de flujo YF-S201

LiquidCrystal_I2C lcd(0x27, 16, 2);

// Variables del sensor de flujo
volatile uint32_t pulsos = 0;
float litros = 0.0;
unsigned long t_anterior = 0;

// ----------------------+
// INTERRUPCIÓN DEL SENSOR
// ----------------------+
void IRAM_ATTR contar_pulso() {
  pulsos++;
}

void setup() {
  Serial.begin(115200);

  // LCD
  lcd.init();
  lcd.backlight();
  lcd.clear();
  lcd.print("Inicializando...");
  delay(1500);

  // Sensor de flujo
  pinMode(SENSOR_FLUJO_PIN, INPUT_PULLUP);
  attachInterrupt(digitalPinToInterrupt(SENSOR_FLUJO_PIN), contar_pulso, RISING);

lcd.clear();
}

void loop() {

  // ----------------------------+
  // CÁLCULO DE FLUJO Y LITROS
  // ----------------------------+
  if (millis() - t_anterior >= 1000) {  // Cada 1 segundo
    noInterrupts();
    uint32_t pulsos_medidos = pulsos;
    pulsos = 0;
    interrupts();

    // Fórmula del YF-S201 (aprox) → 7.5 Hz por L/min
    float caudal_Lmin = pulsos_medidos / 7.5;

    // Litros en 1 segundo (L/min / 60)
    float litros_seg = caudal_Lmin / 60.0;

    litros += litros_seg;

    // ----------------------------+
    // MOSTRAR EN LCD
    // ----------------------------+
    lcd.clear();
    lcd.setCursor(0, 0);
    lcd.print("Flujo:");
    lcd.print(caudal_Lmin, 1);
    lcd.print(" L/m");

    lcd.setCursor(0, 1);
    lcd.print("Litros:");
    lcd.print(litros, 2);

    t_anterior = millis();
  }

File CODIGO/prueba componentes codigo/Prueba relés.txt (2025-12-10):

#define RELE1 14
#define RELE2 27
#define RELE3 26

void setup() {
  Serial.begin(115200);

  pinMode(RELE1, OUTPUT);
  pinMode(RELE2, OUTPUT);
  pinMode(RELE3, OUTPUT);

  // IMPORTANTE: depende del módulo rele
  // Si tu relé es activo en LOW, los apagamos así:
  digitalWrite(RELE1, HIGH);
  digitalWrite(RELE2, HIGH);
  digitalWrite(RELE3, HIGH);

  Serial.println("Iniciando prueba de reles...");
}

void loop() {
  // Encender todos
  Serial.println("ENCENDIENDO RELES");
  digitalWrite(RELE1, LOW);
  digitalWrite(RELE2, LOW);
  digitalWrite(RELE3, LOW);
  delay(2000);

  // Apagar todos
  Serial.println("APAGANDO RELES");
  digitalWrite(RELE1, HIGH);
  digitalWrite(RELE2, HIGH);
  digitalWrite(RELE3, HIGH);
  delay(2000);
}

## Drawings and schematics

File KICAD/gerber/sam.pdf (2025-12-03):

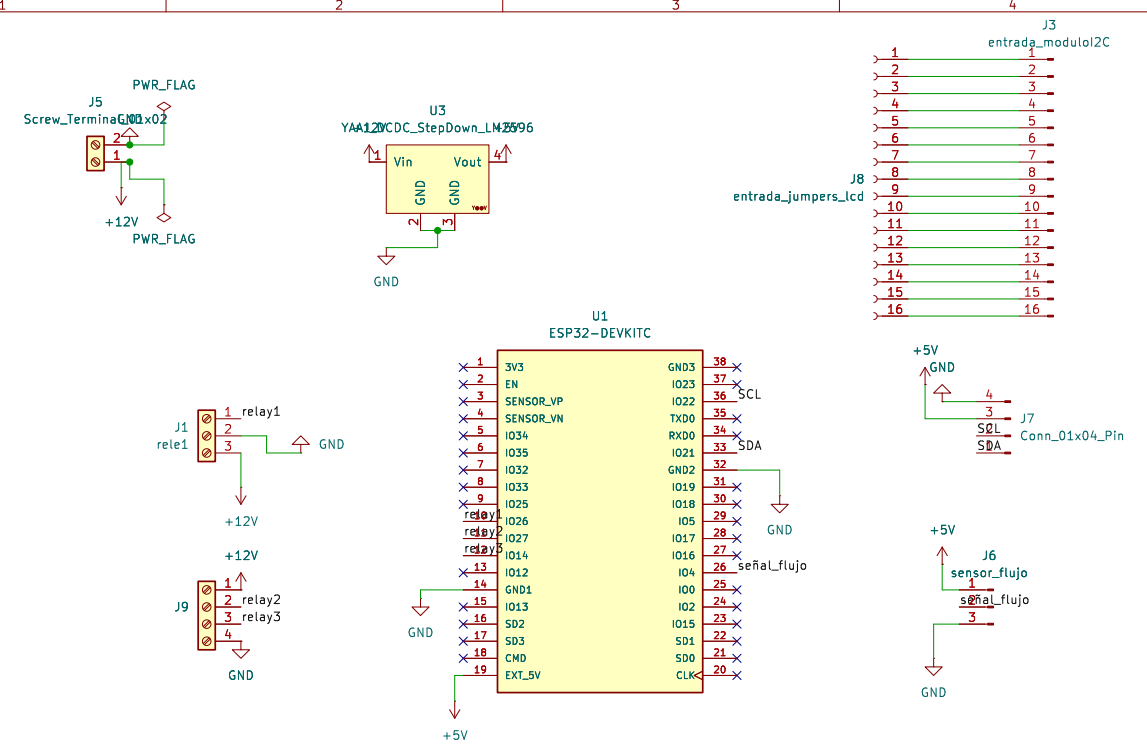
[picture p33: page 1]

Id: 1/1 Title: File: sam.kicad_sch Sheet: /

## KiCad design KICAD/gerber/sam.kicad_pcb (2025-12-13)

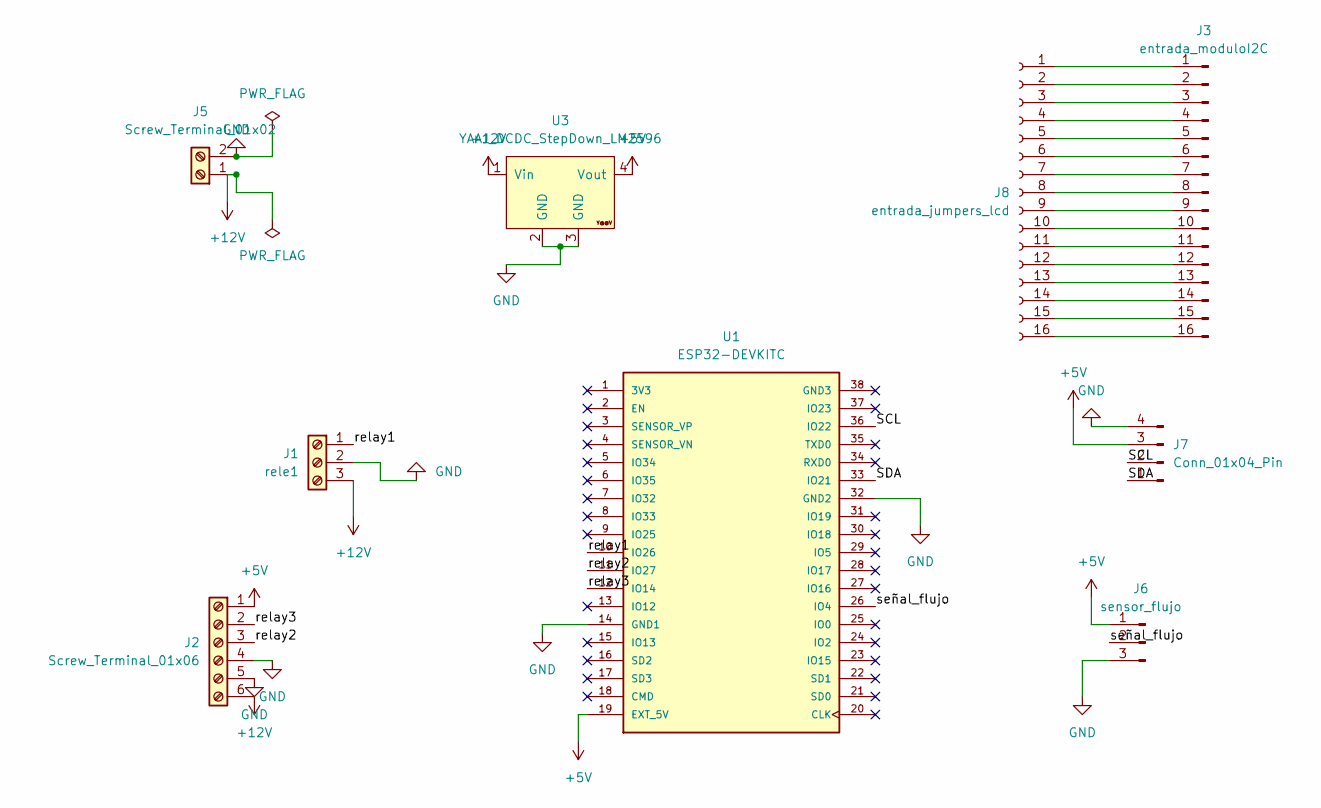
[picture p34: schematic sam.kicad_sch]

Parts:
J1: rele1; TerminalBlock_Xinya_XY308-2.54-3P_1x03_P2.54mm_Horizontal
J2: Screw_Terminal_01x06; TerminalBlock_Phoenix_MPT-0,5-6-2.54_1x06_P2.54mm_Horizontal
J3: entrada_moduloI2C; Molex_SL_171971-0016_1x16_P2.54mm_Vertical
J5: Screw_Terminal_01x02; TerminalBlock_Phoenix_MPT-0,5-2-2.54_1x02_P2.54mm_Horizontal
J6: sensor_flujo; PinHeader_1x03_P2.54mm_Vertical
J7: Conn_01x04_Pin; PinSocket_1x04_P2.54mm_Vertical
J8: entrada_jumpers_lcd; PinSocket_1x16_P2.54mm_Vertical
U1: ESP32-DEVKITC; MODULE_ESP32-DEVKITC; PARTREV N/A
U3: YAAJ_DCDC_StepDown_LM2596

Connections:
+5V: J2.1, J6.1, J7.3, U1.19 (EXT_5V), U3.4 (Vout)
+12V: J1.3, J2.6, J5.1, U3.1 (Vin)
/SCL: J7.2, U1.36 (IO22)
/SDA: J7.1, U1.33 (IO21)
/relay1: J1.1, U1.10 (IO26)
/relay2: J2.3, U1.11 (IO27)
/relay3: J2.2, U1.12 (IO14)
/señal_flujo: J6.2, U1.26 (IO4)
GND: J1.2, J2.4, J2.5, J5.2, J6.3, J7.4, U1.14 (GND1), U1.32 (GND2), U3.2 (GND), U3.3 (GND)
unnamed: J3.1, J8.1
unnamed: J3.2, J8.2
unnamed: J3.3, J8.3
unnamed: J3.4, J8.4
unnamed: J3.5, J8.5
unnamed: J3.6, J8.6
unnamed: J3.7, J8.7
unnamed: J3.8, J8.8
unnamed: J3.9, J8.9
unnamed: J3.10, J8.10
unnamed: J3.11, J8.11
unnamed: J3.12, J8.12
unnamed: J3.13, J8.13
unnamed: J3.14, J8.14
unnamed: J3.15, J8.15
unnamed: J3.16, J8.16

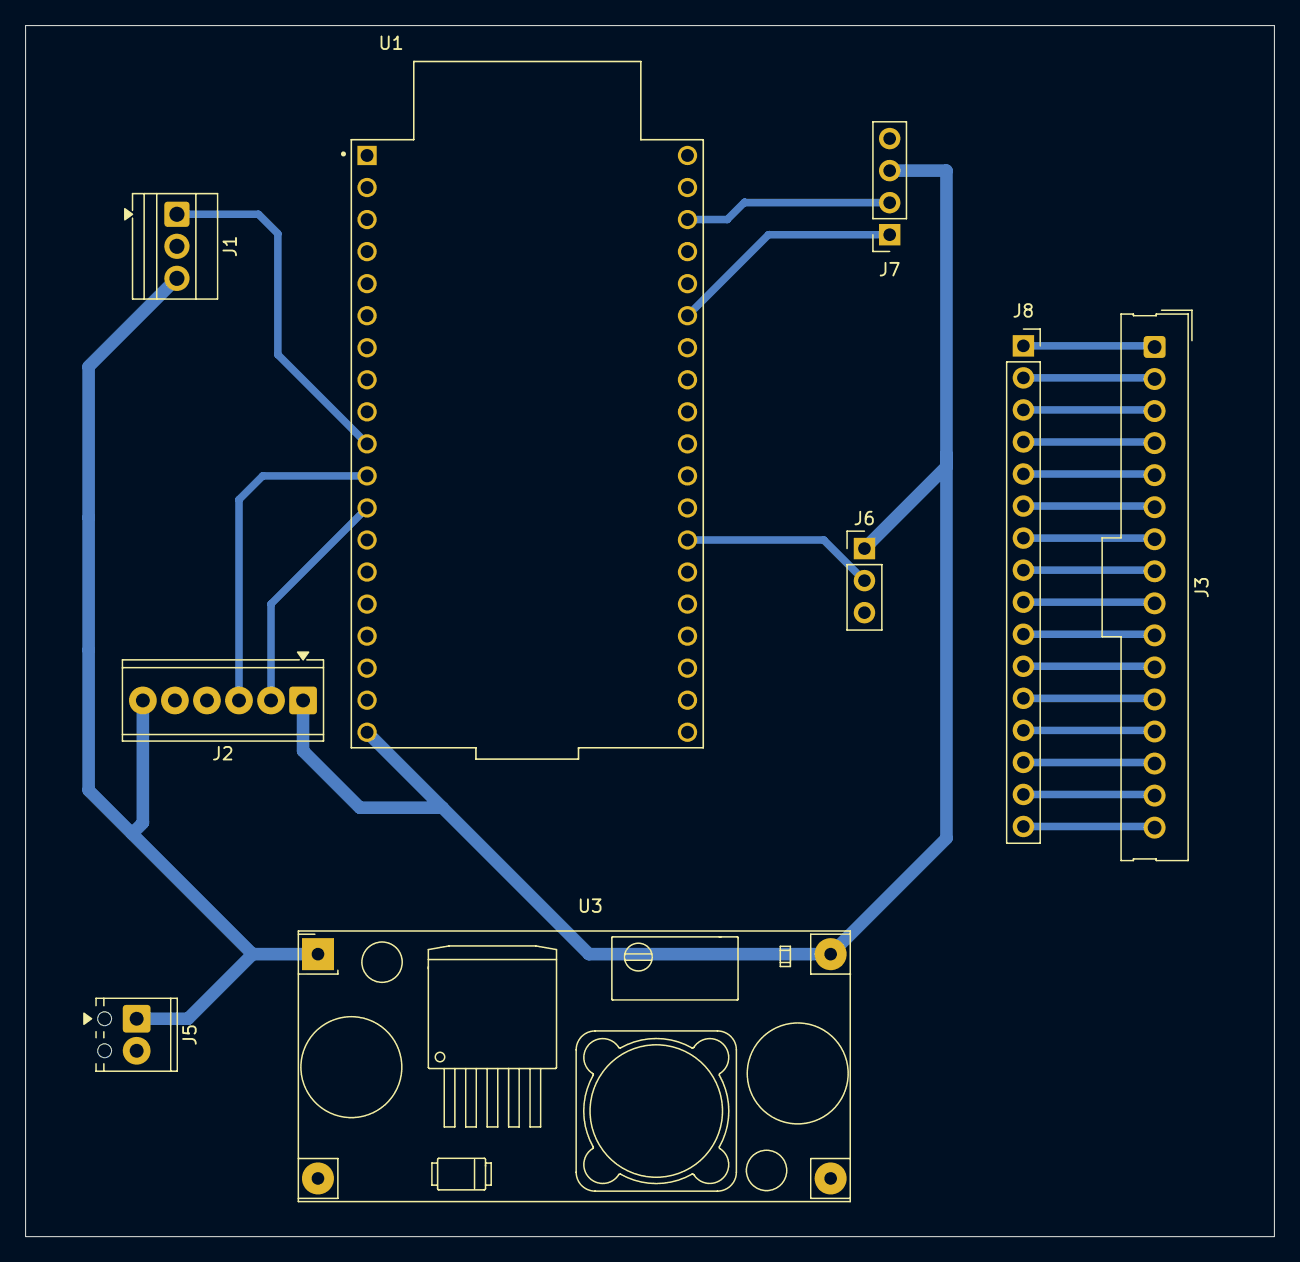
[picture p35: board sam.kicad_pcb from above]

Board: 2 copper layers, 99.0 x 96.0 mm, 9 parts (0 on the bottom side), 25 nets.

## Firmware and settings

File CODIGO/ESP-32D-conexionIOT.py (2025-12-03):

#define BLYNK_TEMPLATE_ID "TMPL2-9qBlvBY"
#define BLYNK_TEMPLATE_NAME "Control de Riego"
#define BLYNK_AUTH_TOKEN "LrsTcscLCbu88JzNmzmm6k4DS6pdao5A"

#include <Wire.h>
#include <WiFi.h>
#include <WiFiClient.h>
#include <BlynkSimpleEsp32.h>
#include <Preferences.h>
#include <LiquidCrystal_I2C.h>

char auth[] = BLYNK_AUTH_TOKEN;
char WIFI[] = "A35";
char PASS[] = "Avlal090";

const uint8_t DATA = 4;
const uint8_t RELAY1 = 14;
const uint8_t RELAY2 = 27;
const uint8_t RELAY3 = 26;

LiquidCrystal_I2C lcd(0x27, 16, 2);

const float PULSES = 7.5;
volatile unsigned int pulse = 0;

float Lpm = 0.0;
float Lps = 0.0;
double total = 0.0;
double waterLimit = 0;
bool limitNotified = false;

unsigned long lastSave = 0;

const int RelayActive = LOW;

#define FLOWLPM V1
#define TOTALL V2
#define VALVE3 V5
#define SOURCE V6
#define LIMIT_SET V11
#define RESET_TOTAL V12

BlynkTimer timer;
Preferences prefs;

void IRAM_ATTR pulseISR() {
  pulse++;
}

void setValve(uint8_t valvePin, bool open) {
  digitalWrite(valvePin, open ? RelayActive : !RelayActive);
}

bool readValveState(uint8_t valvePin) {
  return (digitalRead(valvePin) == RelayActive);
}

BLYNK_WRITE(VALVE3) { setValve(RELAY3, param.asInt() == 1); }

BLYNK_WRITE(LIMIT_SET) {
  waterLimit = param.asDouble();
  prefs.putDouble("limit", waterLimit);
  limitNotified = false;
}

BLYNK_WRITE(RESET_TOTAL) {
  if (param.asInt() == 1) {
    total = 0.0;
    prefs.putDouble("totalL", total);
    Blynk.virtualWrite(TOTALL, total);
    lcd.setCursor(0, 1);
    lcd.print("Tot: 0.0 L     ");
    Serial.println("Total reiniciado desde Blynk");
  }
}
BLYNK_WRITE(SOURCE) {
  int option = param.asInt();

  if (option == 1) {
    setValve(RELAY1, true);
    setValve(RELAY2, false);
  }
  else if (option == 2) {
    setValve(RELAY1, false);
    setValve(RELAY2, true);
  }
}

BLYNK_CONNECTED() {
  Serial.println("Conectado a Blynk!");
  Blynk.syncAll();
  Blynk.virtualWrite(LIMIT_SET, waterLimit);
}

bool leak = false;
bool leakNotified = false;
int leakConfirmCount = 0;
const int LEAK_CONFIRM_THRESHOLD = 2;
int leakClearCount = 0;
const int LEAK_CLEAR_THRESHOLD = 2;

void measureAndPublish() {
  noInterrupts();
  unsigned int pulses = pulse;
  pulse = 0;
  interrupts();

  Lpm = ((float)pulses) / PULSES;
  Lps = Lpm / 60.0;
  total += Lps;

  if (waterLimit > 0 && total >= waterLimit && !limitNotified) {
    limitNotified = true;
    Blynk.logEvent("limite_agua", "Se superó el límite de consumo configurado");
    lcd.clear();
    lcd.setCursor(0, 0);
    lcd.print("LIMITE SUPERADO");
  }

  bool v3 = readValveState(RELAY3);

  if (Lps > 0.01 && !v3) {  
    leakConfirmCount++;
    leakClearCount = 0;
    if (leakConfirmCount >= LEAK_CONFIRM_THRESHOLD) leak = true;
} 
else {
    leakClearCount++;
    leakConfirmCount = 0;
    if (leakClearCount >= LEAK_CLEAR_THRESHOLD) leak = false;
}

  if (leak && !leakNotified) {
    leakNotified = true;
    Blynk.logEvent("alerta_de_fuga", "Alerta: Posible fuga detectada");
  } else if (!leak && leakNotified) {
    leakNotified = false;
    Blynk.logEvent("alerta_de_fuga", "La fuga ha cesado");
  }

  Blynk.virtualWrite(FLOWLPM, Lpm);
  Blynk.virtualWrite(TOTALL, total);

  lcd.setCursor(0, 0);
  lcd.print("Flow:");
  lcd.print(Lpm, 2);
  lcd.print(" L/m   ");
  lcd.setCursor(0, 1);
  lcd.print("Tot:");
  lcd.print(total, 1);
  lcd.print(" L    ");
}

void saveState() {
  unsigned long now = millis();
  if (now - lastSave >= 60000UL) {
    lastSave = now;
    prefs.putDouble("totalL", total);
  }
}

void setup() {
  Serial.begin(115200);
  delay(200);

  pinMode(DATA, INPUT_PULLUP);
  attachInterrupt(digitalPinToInterrupt(DATA), pulseISR, RISING);

  pinMode(RELAY1, OUTPUT);
  pinMode(RELAY2, OUTPUT);
  pinMode(RELAY3, OUTPUT);
  digitalWrite(RELAY1, !RelayActive);
  digitalWrite(RELAY2, !RelayActive);
  digitalWrite(RELAY3, !RelayActive);

  Wire.begin(21, 22);
  lcd.init();
  lcd.backlight();
  lcd.setCursor(0, 0);
  lcd.print("Iniciando...");
  lcd.setCursor(0, 1);
  lcd.print("ESP32 Riego");

  prefs.begin("waterProj", false);
  total = prefs.getDouble("totalL", 0.0);
  waterLimit = prefs.getDouble("limit", 0.0);

  lcd.clear();
  lcd.setCursor(0, 0);
  lcd.print("Conectando WiFi");

  WiFi.begin(WIFI, PASS);
  unsigned long start = millis();
  while (WiFi.status() != WL_CONNECTED && millis() - start < 15000) {
    delay(300);
    Serial.print(".");
  }

  lcd.clear();
  if (WiFi.status() == WL_CONNECTED) lcd.print("WiFi OK");
  else lcd.print("Sin WiFi");

  WiFi.mode(WIFI_STA);

  Blynk.config(auth);
  Blynk.connect();

  timer.setInterval(1000, measureAndPublish);
  timer.setInterval(60000, saveState);

  delay(1000);
  lcd.clear();
}

void loop() {
  if (WiFi.status() != WL_CONNECTED) WiFi.begin(WIFI, PASS);
  if (!Blynk.connected()) Blynk.connect(500);

  Blynk.run();
  timer.run();
}

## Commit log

2025-12-03 Create CODIGO-ESP32D
2025-12-03 Create KICAD
2025-12-03 Update and rename CODIGO-ESP32D to CODIGO-ESP32D.py
2025-12-10 Create prueba sensor flujo
